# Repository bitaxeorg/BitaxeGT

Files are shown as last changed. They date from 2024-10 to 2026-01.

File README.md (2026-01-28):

# Bitaxe Gamma Turbo

Bitaxe Gamma Turbo is a dual BM1370 Open Source Bitcoin miner using [esp-miner](https://github.com/bitaxeorg/esp-miner). This project aims to provide a high-performance, energy-efficient Bitcoin mining solution using modern ASIC hardware.

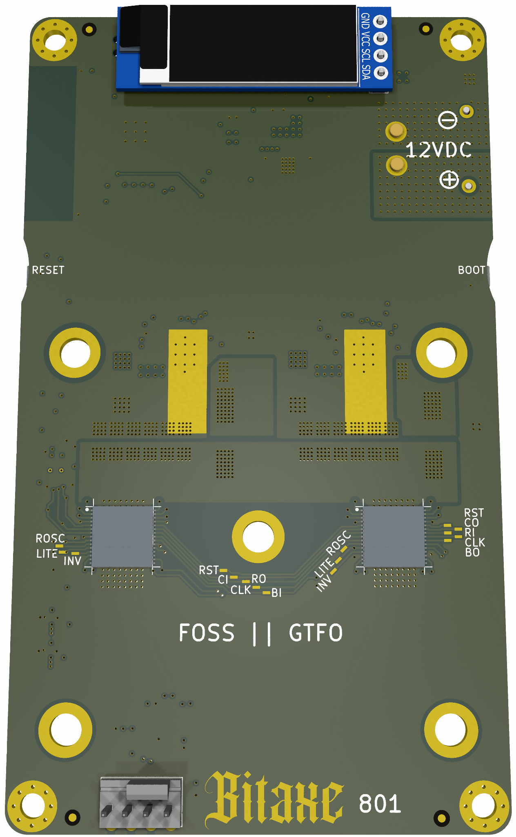
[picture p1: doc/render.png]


## Table of Contents

- [Version](#version)
- [Features](#features)
- [Contributing](#contributing)
- [License](#license)
- [Acknowledgments](#acknowledgments)

## Version

The first release of the Bitaxe Gamma Turbo (GT) marks the version 801.

Major improvements over the version 800xxx are changes in the selected components and refitting components and headers on the PCB.

## Features

- Dual BM1370 ASIC
- Dual TPS546*
- Improved Mounting Hole selection
- 12V BAP
- EMC2103

The Bitaxe Gamma Turbo is the first iteration of a dual ASIC chip variant and marks the first point of multi-chip devices with modern ASIC hardware.

## Contributing

We welcome contributions to the Bitaxe Gamma Turbo project! To contribute, follow these steps:

1. Fork the repository.
2. Create a new branch for your feature or bug fix:
   ```bash
   git checkout -b feature/your-feature-name
   ```
3. Make your changes and commit them:
   ```bash
   git commit -m "Add your commit message here"
   ```
4. Push your changes to your fork:
   ```bash
   git push origin feature/your-feature-name
   ```
5. Create a pull request on the main repository.

## License

This project is licensed under the CERN-OHL-2-S License - see the [LICENSE](LICENSE) file for details.

## Acknowledgments

We would like to acknowledge the following projects and individuals for their contributions to the Bitaxe Gamma Turbo:

- [esp-miner](https://github.com/bitaxeorg/esp-miner) for the mining firmware.
- The open-source community for their support and contributions.

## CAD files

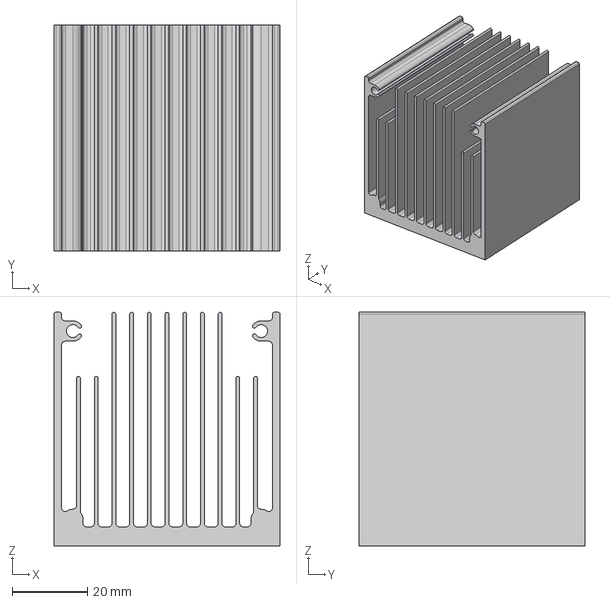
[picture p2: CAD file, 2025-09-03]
3d/GT heatsink.step
60.0 x 60.0 x 62.0 mm

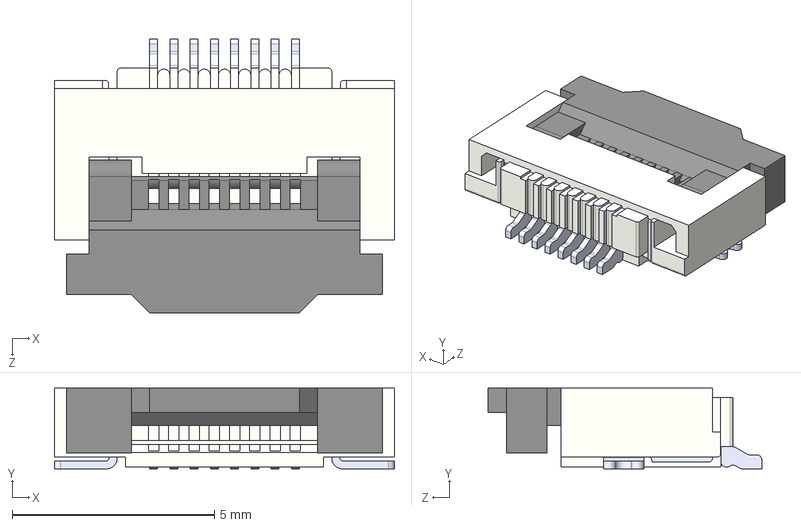
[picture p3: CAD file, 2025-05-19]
3d/FFC2B35-08-T.STEP
8.40 x 2.00 x 6.76 mm

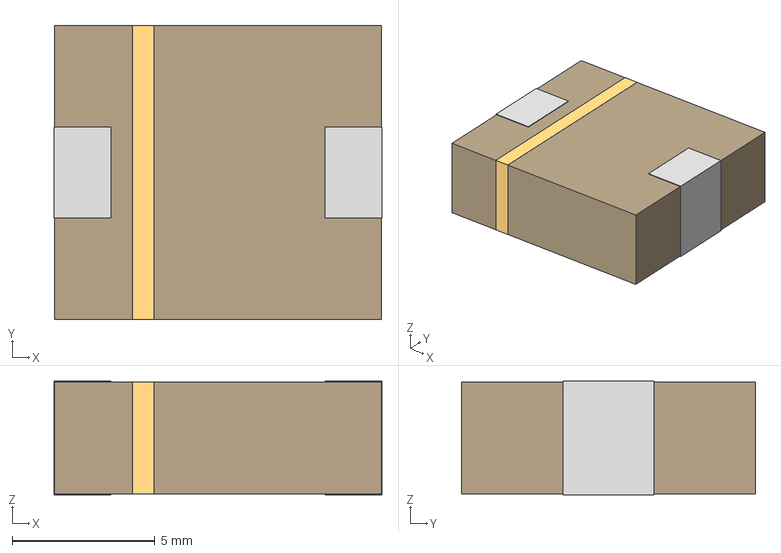
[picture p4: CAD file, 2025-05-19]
3d/IND_-1R5MC_SUM.step
11.5 x 10.3 x 3.99 mm

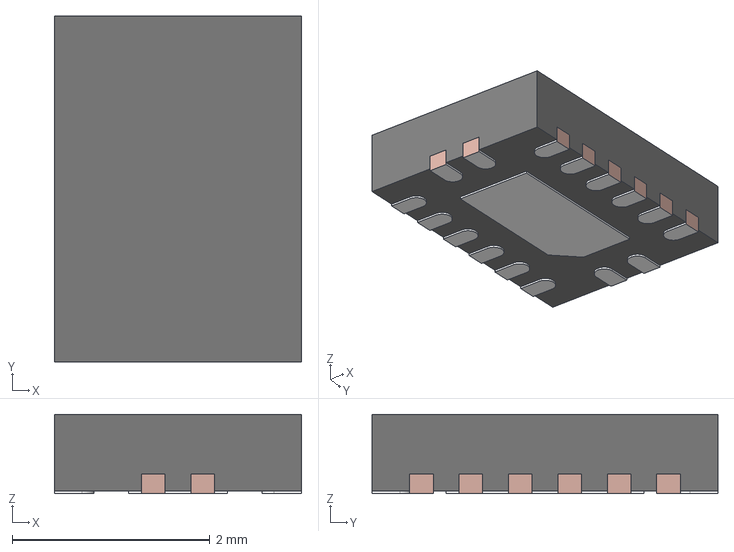
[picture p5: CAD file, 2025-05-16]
3d/BQB0016A.stp
2.50 x 3.50 x 0.8 mm
FRAME

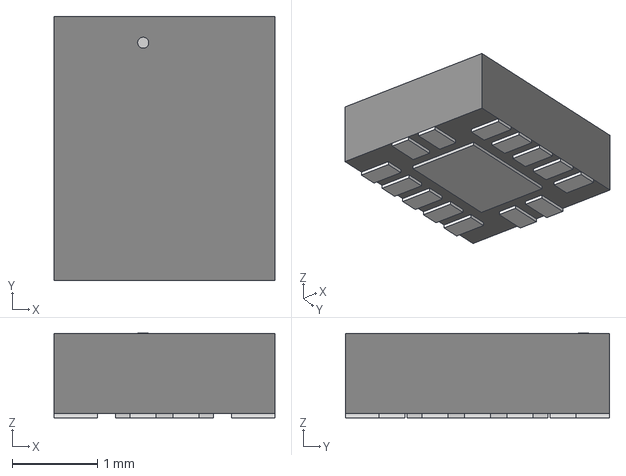
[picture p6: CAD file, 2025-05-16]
3d/DHVQFN14_SOT762-1_NEX.step
2.59 x 3.10 x 0.993 mm

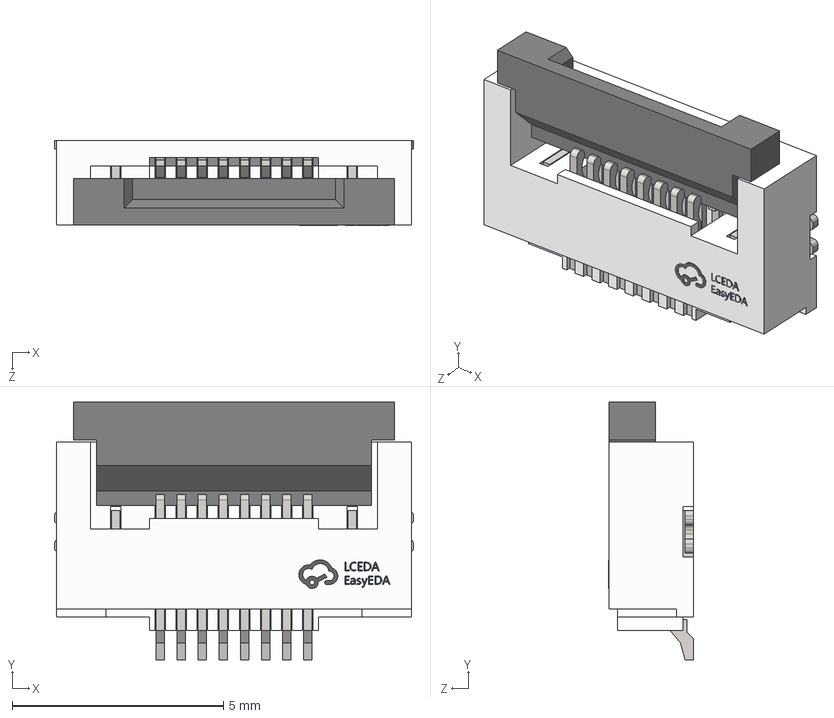
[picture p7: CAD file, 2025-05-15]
3d/FPC-SMD_P0.50-8P_FGS-XJ-H2.0.step
8.50 x 6.10 x 2.01 mm

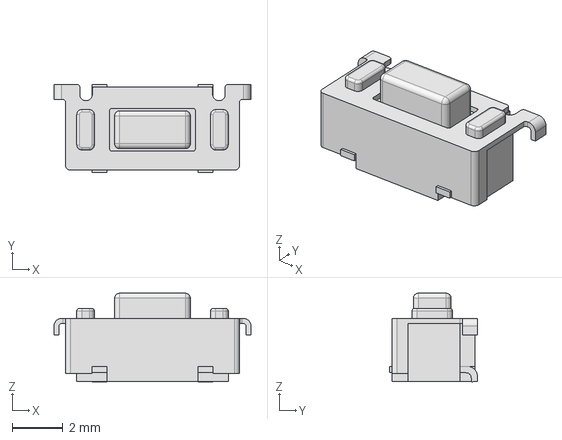
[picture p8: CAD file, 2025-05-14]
3d/141_TL3330AFxxxQG.stp
7.80 x 3.50 x 3.51 mm

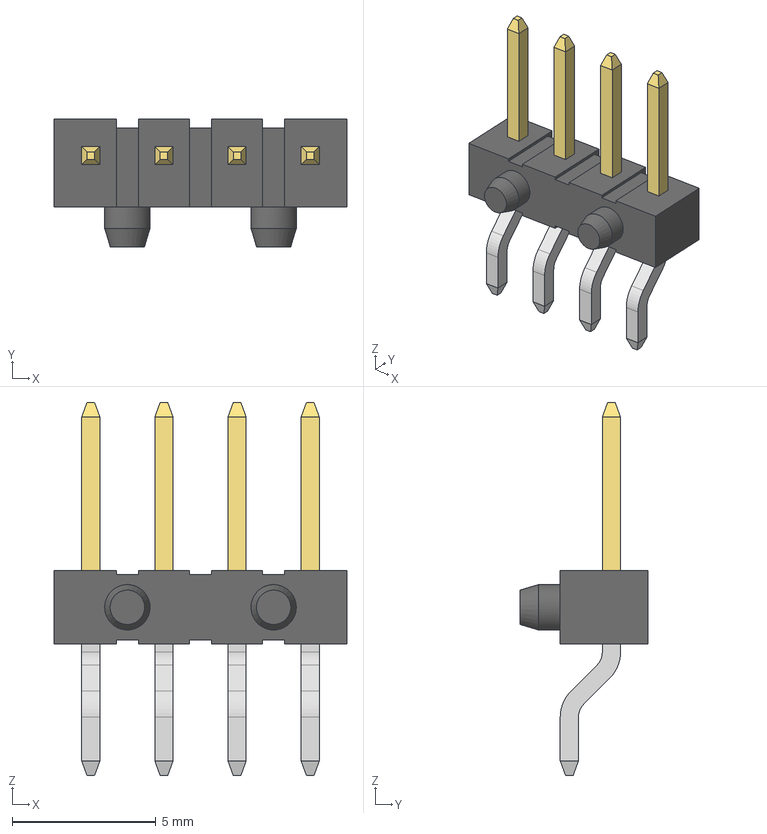
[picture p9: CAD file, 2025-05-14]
3d/TSM-104-01-L-SH-A.stp
10.2 x 4.44 x 13.0 mm
TSM-104-01-SH-A_body
T-1S6-08-L(-01-4-SH)
T-1S6-08-L(-01-4-SH)2

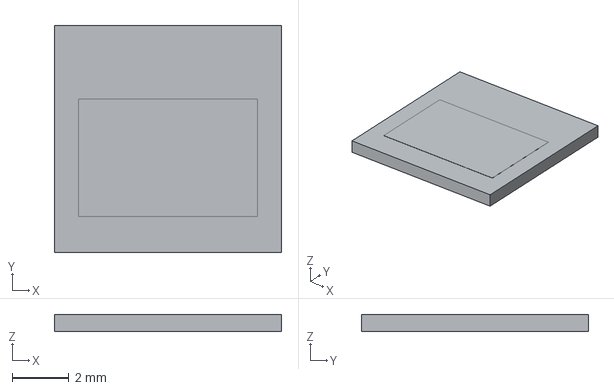
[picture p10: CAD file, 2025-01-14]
3d/bm1370.step
8.00 x 8.00 x 0.61 mm

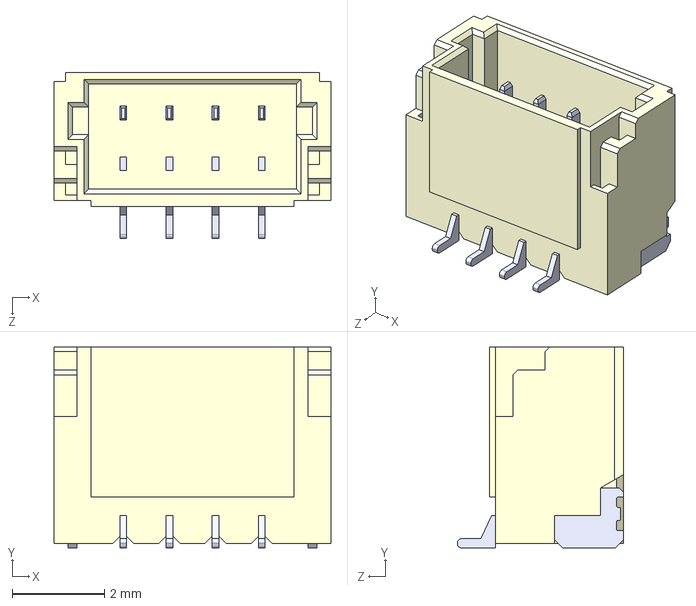
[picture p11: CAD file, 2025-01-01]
3d/BM04B-SRSS-TB.STEP
6.00 x 4.35 x 3.60 mm

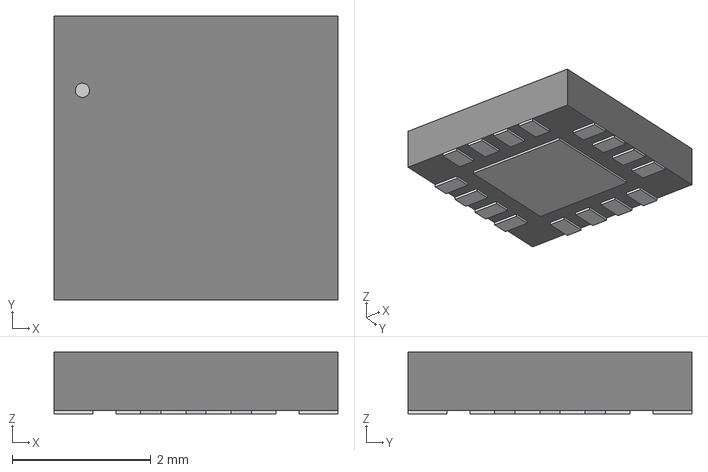
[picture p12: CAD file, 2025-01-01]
3d/QFN16_4X4_MCH.step
4.09 x 4.09 x 0.892 mm

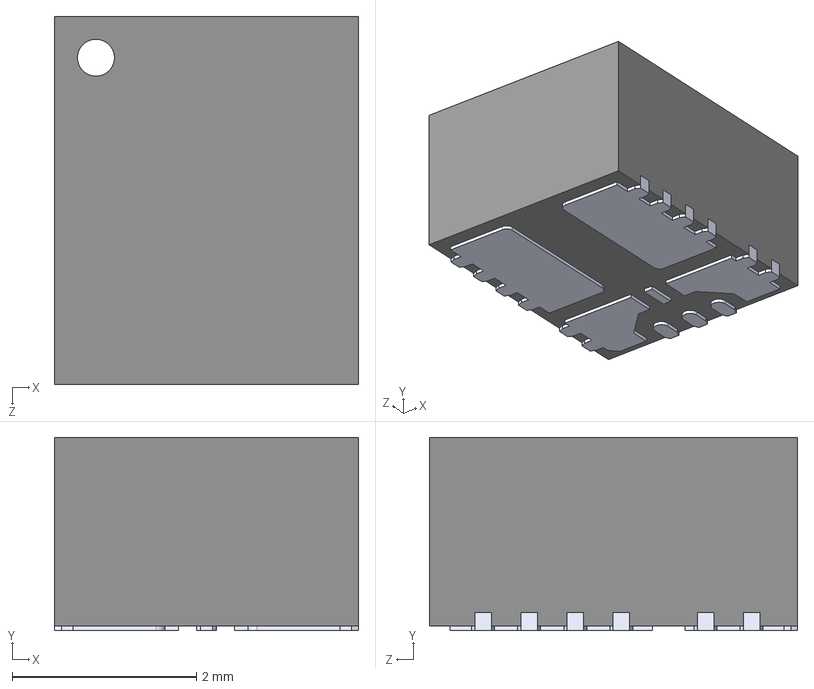
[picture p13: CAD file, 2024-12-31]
3d/TPSM863257RDXR--3DModel-STEP-510211.STEP
3.30 x 2.10 x 4.00 mm

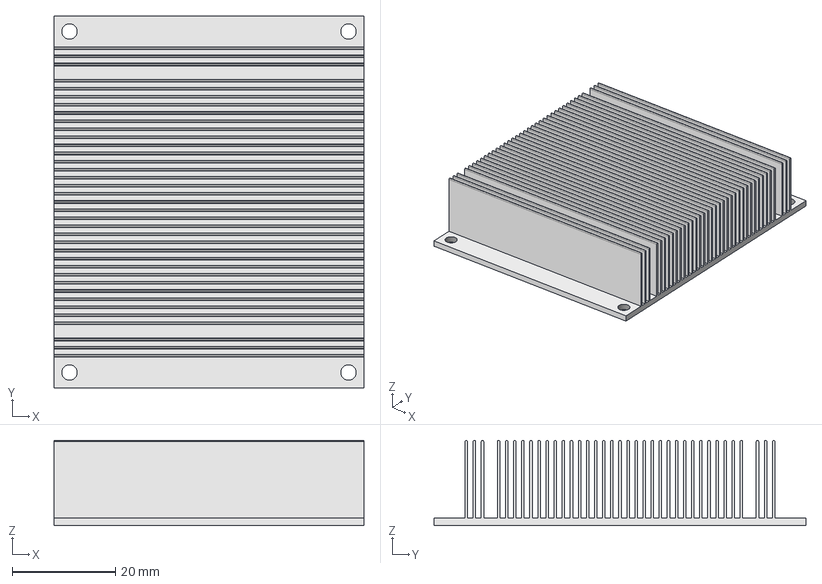
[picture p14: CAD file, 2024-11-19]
3d/BitaxeGT_heatsink.step
60.0 x 72.0 x 16.5 mm

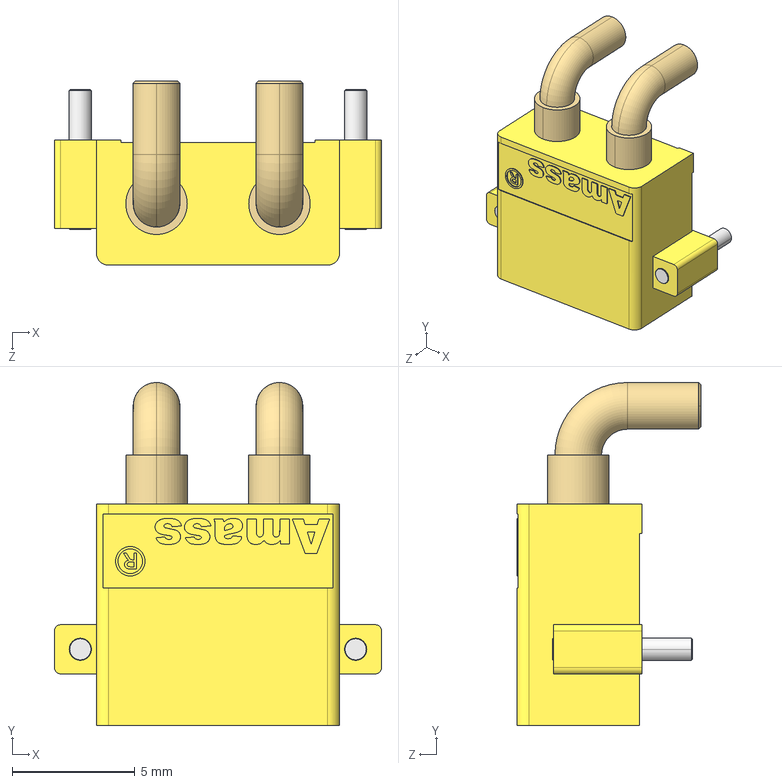
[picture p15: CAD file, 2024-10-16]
3d/XT30PW-M.stp
13.3 x 13.9 x 7.50 mm

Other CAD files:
3d/DISST7789-176x320.STEP
3d/TXB0104RGYR.STEP
3d/ESP32-S3-WROOM-1-N8R2--3DModel-STEP-56544.STEP
3d/TPS546D24ARVFR.step
3d/21-0164B_L622-1_MXM.step
3d/2R5TPE220MAFB.step
3d/470531000.stp
3d/54-00164.STEP
3d/BM1368xx.stp
3d/Bitaxe_Heatsink.step
3d/CS1213AG-tr.stp
3d/CUI_DEVICES_PJ-002AH.step
3d/CUI_DEVICES_PJ-036AH-SMT-TR.step
3d/CUI_DEVICES_PJ-037AH.step
3d/CX3225SB16000H0FLJCC.STEP
3d/Coilcraft-SLC1175.STEP
3d/Cree_PLCC6.stp
3d/DQG0008A.stp
3d/DQH0008A.stp
3d/DRC0010J.stp
3d/DRL0006A.stp
3d/FP1006V2-R.STEP
3d/FTSH-105-01-F-DV-K.stp
3d/IHLP2020CZ.step
3d/OLED_0.91_128x32.stp
3d/PLCC6_LED_3_5X3_4X2_8_CRW.step
3d/SLC1175-271MEC_COC.step
3d/SMV_z90.stp
3d/SN74AXC1T45DBVR.STEP
3d/SOT-23-5_M5_MCH.step
3d/ST-4ETB2k_(202).stp
3d/SW_CS1213AGF260_CRS.step
3d/TSOT-23-5_RIT.step
3d/USB_10118193-0001LF.STEP
3d/XRCGB27M120F3M10R0_MUR.step
3d/XTAL_SC32S-7PF20PPM_EPS.step
3d/c-63862-1-r-3d.stp
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

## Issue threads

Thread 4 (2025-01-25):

add button labels to silkscreen

skot, 2025-01-25:
probably `RESET` and `BOOT`

Closed 2025-05-03.

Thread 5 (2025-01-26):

JST Fan connector pinout is wrong

macphyter, 2025-01-26:
The pinout on J6 JST fan connector is backwards.

skot, 2025-02-28:
looks like this was fixed in 18f2bdc

Closed 2025-05-03.

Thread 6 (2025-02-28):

build better buttons

skot, 2025-02-28:
The RESET and BOOT buttons are pretty small, maybe we could find some better ones onw that we have more space on the topside of the PCB? Also they could be in a better location

benjamin-wilson, 2025-03-01:
Yes! Horizontal buttons would work well to so they're compatible with cases

benjamin-wilson, 2025-03-01:
Check out BAP display buttons

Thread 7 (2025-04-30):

Bitaxe is not detected when connected to a USB-C port

rkuester, 2025-04-30:
A Bitaxe Gamma is not detected when connected to an upstream USB-C port.  See bitaxeorg/bitaxeGamma#37.

I have not encountered this issue firsthand; however, looking at the current GT schematic, I presume it also has this issue.

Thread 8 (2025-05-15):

Display falls out

jeffersonwarrior, 2025-05-15:
The display falls out so easily. As much as I am loathe to add any kind of build requirement, it needs something. A paperclip would be better than losing a whole display in a box that was accidentally thrown out.

skot, 2025-05-15:
I hear ya. The current display connector is very far from ideal. The main issue right now is that we don't have any control over the design of the display module/pcb/connector. We could easily make our own, but that will raise prices and reduce availability.

I think longer term the solution is to use the bare OLED directly on the Bitaxe. This will increase the price, complexity and decrease availability, but hopefully not tooo much.

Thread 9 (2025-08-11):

800xxx does not boot with R7 installed.

skot, 2025-08-11:
A user reported this to me;

the 800xxx schematic shows R7 at 14.7k;

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

But with this strapping resistor soldered in place the bitaxe doesn't boot. Removing the resistor and the Bitaxe boots normally (with the exception of https://github.com/bitaxeorg/ESP-Miner/issues/1185)

Interestingly the Webench design has R7 as DNP. (Rmsel1t)

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

skot, 2025-09-01:
> It is my understanding that these strapping resistors set the default config of the VR. We always manually config the TPS546 over I2C anyways, so it would seem like none of them are needed. But I'd like to test and understand this more before making that call.

I'm looking into this here; https://github.com/bitaxeorg/BitaxeGT/issues/11

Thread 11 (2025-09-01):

Can we DNP all the TPS546 strapping resistors?

skot, 2025-09-01:
My sense is that the strapping resistors are just to set the default configuration of the [TPS546D24x](https://www.ti.com/lit/ds/symlink/tps546d24a.pdf) voltage regulator. Can we just configure the VR over I2C before enabling it?

skot, 2025-09-01:
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
I think the answer is _yes_. We can leave the pin-stripping resistors (R7, R9, R10, R11, R12 & R13) DNP, as long as we also leave the EN/UVLO pin also floating (DNP R4 & R5). This will cause the TPS546D24x to startup with the output disabled, waiting for configuration at the default PMBus address (default slave address 0x24 if ADRSEL is floating).

We can still utilize the undervoltage shutdown functionality with a write to (0x5A) VIN_OFF register to set the VIN level below which the regulator shuts down.

We will need to maintain backwards compatibility with any hardware out there that still has these resistors placed. I think we can do this by making sure to disable the TPS546 output right away.

skot, 2025-09-01:
For some reason this isn't working on the bitaxeGamma 601;
```
I (2941) power_management: setting new vcore voltage to 1150mV
I (2942) vcore: Set ASIC voltage = 1.150V
I (2943) TPS546: Vout changed to 1.15 V
E (2947) TPS546: Status: 0x1842
E (2950) TPS546: The voltage regulator is turned off
E (2955) TPS546: A communication, memory, logic fault has occurred
E (2963) TPS546: TPS546 CML Status: 02
E (2967) TPS546: communication error detected
```

I'll have to look into what is different between the 601 and the 800 HW and FW.

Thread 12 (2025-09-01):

Mounting hole

WantClue, 2025-09-01:
Adding another mounting hole in between the asics for better contact and reduction on board bending

powerminingfarm, 2025-09-19:
Is someone working on this or we can make proposal @WantClue ?

powerminingfarm, 2025-09-22:
> > Is someone working on this or we can make proposal [@WantClue](https://github.com/WantClue) ?
>
> I don't think anybody is working on that, whats your proposal?

Looking into this deeper, I don't really see option to add additional mounting hole in the middle + keep same traces as there is not enough space. Are we OK to change the traces / element placement?

Closed 2025-10-03.

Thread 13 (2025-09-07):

Skot I need your help

bjunger83-blip, 2025-09-07:
I found you in github from a post couple of months ago asking someone to send a Bitaxe 601 with flatline of death. I have one of these to send to you if you want. -Brian

skot, 2025-09-07:
Yes definitely! Can you message me on the OSMU Discord? https://discord.gg/osmu

bjunger83-blip, 2025-09-07:
@skot Somehow Discord is even less user friendly than Github. Won't let me post a message, submit a friend request, or now even log in to my account bc of some phone number issue. Can you email me? bjunger83@gmail.com

Closed 2025-09-07.

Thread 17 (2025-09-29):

SYNC_FAULT with TPS546D24A

skot, 2025-09-29:
There appears to be an undocumented silicon-level issue with the TPS546D24**A** variant voltage regulator in a multi-phase setup that results in a SYNC_FAULT shutdown after ~20 minutes of use. The issue does not occur with an otherwise identical PSU, PCB, firmware config but with a TPS546D24**S** fitted. TPS546D24**S** based BitaxeGT builds have run without fault for weeks.

I have not been able to find any combination of TPS546D24 register config register settings that solves this issue with the TPS546D24**A**. Texas Instruments support suggested that this might be a noise issue on the VSHARE, SYNC and/or BCX signals connecting the two phases. Being as this issue does not occur on an identical build with the TPS546D24**S** (and the noise is not significant anyways) this points to a specific issue with the TPS546D24**A**.

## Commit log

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2024-10-18 Add sheets and work on power supply
    [ASIC.kicad_sch, BitaxeGT.kicad_sch, ESP32.kicad_sch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]
2024-10-19 More schematic work for ASICs and ESP32
    [ASIC.kicad_sch, BitaxeGT.kicad_sch, ESP32.kicad_sch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]
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2024-11-03 convert to TPS546 2-phase design
    [Power.kicad_sch]
2024-11-03 add second power phase
    [Power.kicad_sch]
2024-11-04 Finish wiring ASICs and ESP32
    [ASIC.kicad_sch, BitaxeGT.kicad_sch, ESP32.kicad_sch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]
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2024-11-15 change fan controller to EMC2103-2 with two temperature inputs
    [BitaxeGT.kicad_sch, fan.kicad_sch]
2024-11-19 create PCB, add components and heatsink
    [BitaxeGT.kicad_pcb, BitaxeGT.kicad_sch, BitaxeGT_heatsink.step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]
2024-11-26 start rough parts placement
    [ASIC.kicad_sch, BitaxeGT.kicad_pcb, Power.kicad_sch]
2024-11-30 Finish assigning footprints and partnumbers
    [ASIC.kicad_sch, BitaxeGT.kicad_pcb, ESP32.kicad_sch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]
2024-12-01 add VR debug header
    [ESP32.kicad_sch, Power.kicad_sch]
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2024-12-05 Arrange power supply components
    [BitaxeGT.kicad_pcb, Power.kicad_sch]
2024-12-11 more power supply routing
    [ASIC.kicad_sch, BitaxeGT.kicad_pcb, BitaxeGT.kicad_sch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]
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2024-12-17 Place power supply components
    [BitaxeGT.kicad_pcb]
2024-12-18 More power supply placement
    [BitaxeGT.kicad_pcb, Power.kicad_sch]
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2024-12-23 Route main power paths
    [ASIC.kicad_sch, BitaxeGT.kicad_pcb, BitaxeGT.kicad_sch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]
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2024-12-24 New voltage regulator positions, start routing ASICs
    [BitaxeGT.kicad_pcb]
2024-12-26 some power supply routing
    [BitaxeGT.kicad_pcb, ESP32.kicad_sch]
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2024-12-27 move back barrel jack
    [BitaxeGT.kicad_pcb]
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2024-12-28 reorganizing esp and plugs
    [BitaxeGT.kicad_pcb, Power.kicad_sch]
2024-12-28 vias and layers to high current tracks
    [BitaxeGT.kicad_pcb]
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2024-12-30 Tweak one of the current return planes
    [BitaxeGT.kicad_pcb]
2024-12-30 change 10uf to 0402, change decouple caps to 5X10uf
    [ASIC.kicad_sch, BitaxeGT.kicad_pcb, ESP32.kicad_sch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]
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2024-12-30 extend inner plane to provide more GND return
    [BitaxeGT.kicad_pcb]
2024-12-30 Swap ln2 and ln4, DRC fixes
    [BitaxeGT.kicad_pcb]
2024-12-30 move tps remote sense and tie AGND GND
    [BitaxeGT.kicad_pcb]
2024-12-31 Change 3.3V regulator to TPSM861253
    [BitaxeGT.kicad_pcb, Power.kicad_sch, TPSM863257RDXR--3DModel-STEP-510211.STEP]
2024-12-31 Changed 10uf caps to 0603
    [ASIC.kicad_sch, BitaxeGT.kicad_pcb, BitaxeGT.kicad_sch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]
2025-01-01 fixed unused input on level shifter. Attached Vcore to ADC pin on the ESP32 for monitoring.
    [ASIC.kicad_sch, BitaxeGT.kicad_pcb, BitaxeGT.kicad_sch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]
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2025-01-01 moved U2 current sense amp and C21 to the backside
    [BitaxeGT.kicad_pcb]
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2025-01-02 added Vsupply to BAP. Cleaning up library paths. Moving 12V vias out of Bitaxe logo
    [BitaxeGT.kicad_pcb, BitaxeGT.kicad_sch, ESP32.kicad_sch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]
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2025-01-03 BOM additions and fixes
    [BitaxeGT.kicad_pcb, ESP32.kicad_sch]
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2025-02-04 adjust shunt resistor for reasonable sense current range
    [Power.kicad_sch]
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2025-02-05 swap XT30 to front
    [BitaxeGT.kicad_pcb, ESP32.kicad_sch, Power.kicad_sch]
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2025-02-28 fixed 12V / VIN net descrepancy
    [ASIC.kicad_sch, BitaxeGT.kicad_pcb, BitaxeGT.kicad_sch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]
2025-02-28 fixed minor DRC stuff. re-attached BAP VIN. bumped version to 800xx. deleted old gerbers
    [ASIC.kicad_sch, BitaxeGT.kicad_pcb, BitaxeGT.kicad_sch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]
2025-02-28 added fix for #3
    [BitaxeGT.kicad_pcb]
2025-02-28 added fix for #4
    [BitaxeGT.kicad_pcb]
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2025-03-01 open more space for current return path, change inductor footprints back to coilcraft
    [BitaxeGT.kicad_pcb, Power.kicad_sch]
2025-03-16 Changed SMT M3 hole from 4.3 to 4.2mm
    [BitaxeGT.kicad_pcb]
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2025-05-12 add correct button part numbers to BOM
    [ASIC.kicad_sch, BitaxeGT.kicad_sch, ESP32.kicad_sch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]
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2025-05-13 added more metal on TPS546 GND pads, added soldermask keepout for thermal on TPS546
    [ASIC.kicad_sch, BitaxeGT.kicad_pcb, BitaxeGT.kicad_sch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]
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2025-05-13 flipped XT30 to the backside.
    [BitaxeGT.kicad_pcb]
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2025-05-14 add new backside SMD buttons. Add new fan connector experiment (needs work)
    [141_TL3330AFxxxQG.stp, BitaxeGT.kicad_pcb, BitaxeGT.kicad_sch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]
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2025-05-14 moved the fan connector back out for heatsink mounting stability
    [BitaxeGT.kicad_pcb]
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2025-05-16 updated the level shifter to the cheaper, more available SN74AXC4T774BQBR
    [ASIC.kicad_sch, BQB0016A.stp, BitaxeGT.kicad_pcb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]
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2025-05-19 cleaned up BOM and generated output. Cleaned up vias, tracks and generated gerbers
    [ASIC.kicad_sch, BitaxeGT.kicad_pcb, BitaxeGT.kicad_sch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]
2025-05-20 removed fan connector experiment. made fan connector pads longer, centered connector, and made symmetrical. regenerated and checked gerbers.
    [BitaxeGT.kicad_pcb, fan.kicad_sch]
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2025-08-29 Added 10k EMC2103-4 SHDN_SEL strapping resistor for #10. Updated BOM and iBOM
    [BitaxeGT.kicad_pcb, fan.kicad_sch]
2025-09-03 add GT heatsink and single component mounting holes.
    [BitaxeGT.kicad_pcb, BitaxeGT.kicad_sch, GT heatsink.step]
2025-09-03 remove all strapping resistors and EN/UVLO components for #11
    [Power.kicad_sch]
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2025-09-29 changed schematic and BOM to TPS546D24S for #17
    [Power.kicad_sch]
2025-09-29 separated and shielded BCX, VSHARE and SYNC. mostly unbroken GND planes on In1 and In3. Most low power tracks on In2
    [BitaxeGT.kicad_pcb, BitaxeGT.kicad_sch, ESP32.kicad_sch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]
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2025-09-30 remove GND pour from Ln3 and cleanup TPS546D24 SYNC tracks
    [ASIC.kicad_sch, BitaxeGT.kicad_pcb, Power.kicad_sch]
2025-10-01 routed and cleaned up. DRC pass. adjusted vias more. removed old manufacturing files
    [ASIC.kicad_sch, BitaxeGT.kicad_pcb, BitaxeGT.kicad_sch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]
2025-10-01 add topside test points. add button finger indents in edge cut. generate BOM, iBOM and checked gerbers.
    [ASIC.kicad_sch, BitaxeGT.kicad_pcb, BitaxeGT.kicad_sch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]
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2026-03-17 clarified in schematic that EMC2103 temp channel 1 is connected to ASIC 2 and temp channel 2 is connected to ASIC 1
    [ASIC.kicad_sch, BitaxeGT.kicad_pcb, BitaxeGT.kicad_sch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]

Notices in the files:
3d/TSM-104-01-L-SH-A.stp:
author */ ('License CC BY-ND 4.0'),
